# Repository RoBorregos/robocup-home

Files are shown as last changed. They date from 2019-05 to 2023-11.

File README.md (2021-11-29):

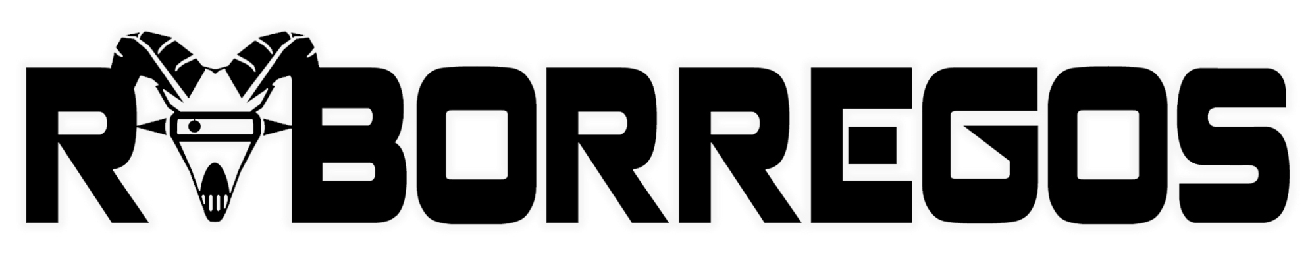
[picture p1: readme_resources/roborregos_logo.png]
 

# RoBorregos Robocup-Home
This repository contains the development of RoBorregos' robotic solution for [RoboCup's @HOME competition](https://athome.robocup.org/), Open Platform League (OPL), where the robot must be capable of interacting with people, manipulate objects and have intelligent responses for everyday home tasks.

See [RoboCup @HOME Rules](https://robocupathome.github.io/RuleBook/rulebook/master.pdf).

## Project setup

1. Clone the project repository on your local machine.

   SSH:

   ```bash
   $ git clone --recurse-submodules https://github.com/RoBorregos/Robocup-Home.git
   ```
2. [Docker Setup If needed](https://github.com/RoBorregos/Robocup-Home/wiki/Docker-Usage)

## Project details

This project is made using:
- [ROS Noetic](https://www.ros.org/)
- [Rasa NLU](https://rasa.com/)
- [Tensorflow](https://www.tensorflow.org/learn)
- [PaddlePaddle](https://github.com/paddlepaddle/paddle)
- [Arduino](https://www.arduino.cc/)
- [VIA EPIA](https://www.viatech.com/en/support/eol/epia-eol/)
- [Jetson](https://developer.nvidia.com/EMBEDDED/jetson-nano-developer-kit)

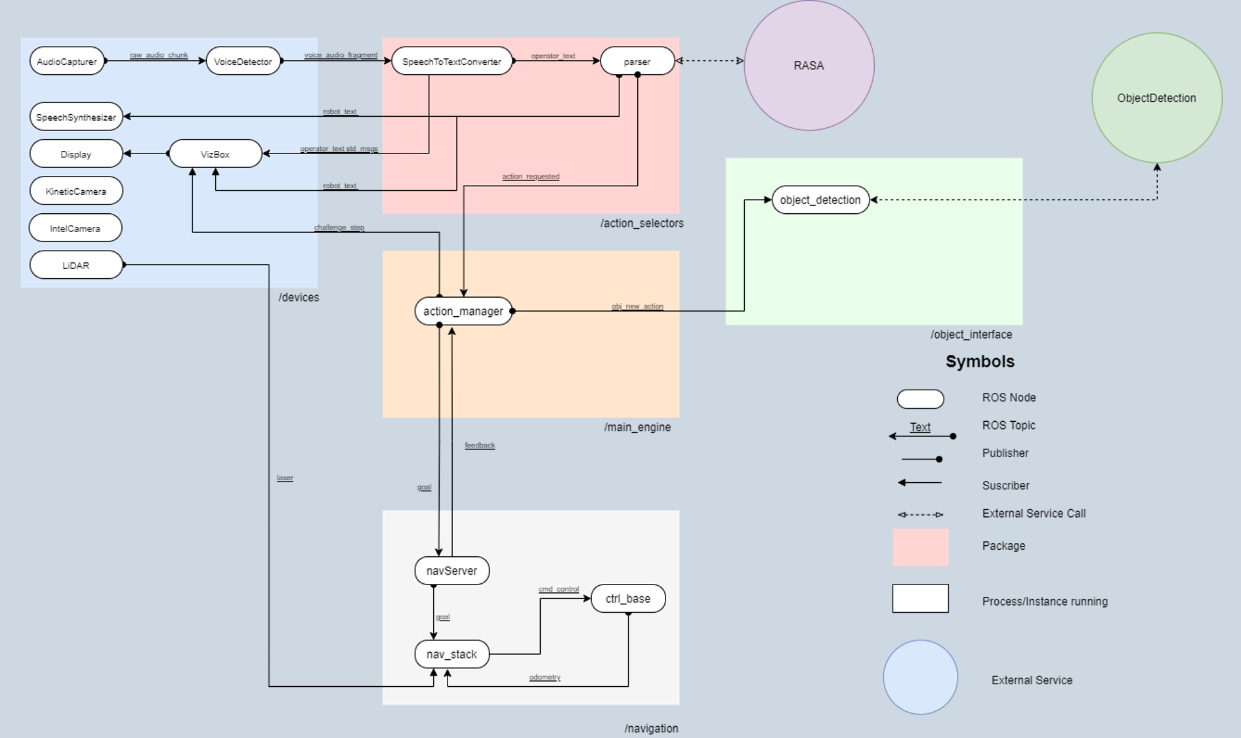
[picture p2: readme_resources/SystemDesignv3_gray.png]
 

For more information about the project system, structure, and development areas you can check our [Official Documentation](https://github.com/RoBorregos/Robocup-Home/wiki).

### Development team

| Name | Email | Github | Role |
| --- | --- | --- | --- |
| José Cisneros | [joseacisnerosm@gmail.com](mailto:joseacisnerosm@gmail.com) | [@Josecisneros001](https://github.com/Josecisneros001) | PM Software, Integration & Speech|
| Aldo Samaniego | [aldojesussam0@gmail.com](mailto:aldojesussam0@gmail.com) | [@AldoSamaniego](https://github.com/AldoSamaniego) | PM Mechatronics & Power Supply Electronics|
| Aurora Tijerina | [auro.tj@gmail.com](mailto:auro.tj@gmail.com) | [@AuroTB](https://github.com/aurotb) | Navigation & Integration |
| Ricardo Chapa | [ricardochaparomero@gmail.com](mailto:ricardochaparomero@gmail.com) | [@RicardoChapaRomero](https://github.com/RicardoChapaRomero) | Object Detection |
| Alejandro Ruiz | [alex.01ruiz@hotmail.com](mailto:alex.01ruiz@hotmail.com) | [@BVDozen](https://github.com/BVDozen) | Mechanical Design |
| Iqui Balam  | [iquibalamhm@gmail.com](mailto:iquibalamhm@gmail.com) | [@IquiBalamHM ](https://github.com/IquiBalamHM ) | Object Detection |
| Amin Mendez | [mendezamin.com@gmail.com](mailto:mendezamin.com@gmail.com) | [@AminMendez](https://github.com/AminMendez) | Mechanical Design | 
| Gaby Alvarez | [gabrielaj.alvarez@outlook.com](mailto:gabrielaj.alvarez@outlook.com) | [@gabyjazzmin ](https://github.com/gabyjazzmin ) |  NLP Conversation |
| Anel Alvarado | [anelgtz01@gmail.com](mailto:anelgtz01@gmail.com) | [@AnelAlvarado ](https://github.com/AnelAlvarado ) | Elevator Electronics |
| José Pacheco | [pacocheco7@gmail.com](mailto:pacocheco7@gmail.com) | [@JFPach98 ](https://github.com/JFPach98 ) | Human Detection |
| Alonso Ruiz | [alonsort11@gmail.com](mailto:alonsort11@gmail.com) | [@AlonRuiz](https://github.com/AlonRuiz) | Arm Mechanics |
| Andy Salcedo | [andrea2702@gmail.com](mailto:andrea2702@gmail.com) | [@andrea2702](https://github.com/andrea2702) | Arm Electronics |
| Ignacio Maldonado | [igna-tenkov@gmail.com](mailto:igna-tenkov@gmail.com) | [@IGNA-TENKOV](https://github.com/IGNA-TENKOV) | Mechanical Design |
| Paul Vazquez | [pev@live.com.mx](mailto:pev@live.com.mx) | [@paulvazbad](https://github.com/paulvazbad) | Mentor |

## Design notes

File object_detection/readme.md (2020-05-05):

# Train the Object Detection TF API from scratch using Google Colab
We are using the [TensorFlow Object Detection API](https://github.com/tensorflow/models/tree/master/research/object_detection) to retrain the models with the objects that we need. Check installation and more info there. All this has been tried for python2/3 and tensorflow==1.15.

[Colab](http://colab.research.google.com/) offers free access to a computer that has reasonable GPU good for training, it is a cloud service based on Jupyter Notebooks and internet connectivity is required for access.

## Preprocessing

The first step is to take pictures of the objects to train, after doing that, you have to reduce the resolution of the pictures (this reduces training time) and split the images into train/test folders.

run the [transform_image_resolution.py](https://github.com/RoBorregos/Robocup-Home/tree/develop/object_detection/scripts/transform_image_resolution.py) script:
```bash
python transform_image_resolution.py -d ../images/ -s 800 600
```
- `-d` is the directory containing all the images.
- `-s` is the resolution that will be applied to the images.

run the [split_images](https://github.com/RoBorregos/Robocup-Home/tree/develop/object_detection/scripts/split_images.py) script.
```bash
python split_images.py -d ../images/complete_dataset -o ../images --train 80
```
- `-d` is the directory containing all the images.
- `-o` is the directory where the train and test folder will be created.
- `--train` is the percentage of images that will be used for training, 80% for train and %20 for test is the recommended. 

Now you need to label the images, use the [labelimg](https://github.com/tzutalin/labelImg) open source tool to label all the pictures in both train/test directories (this is a tedious and long process).

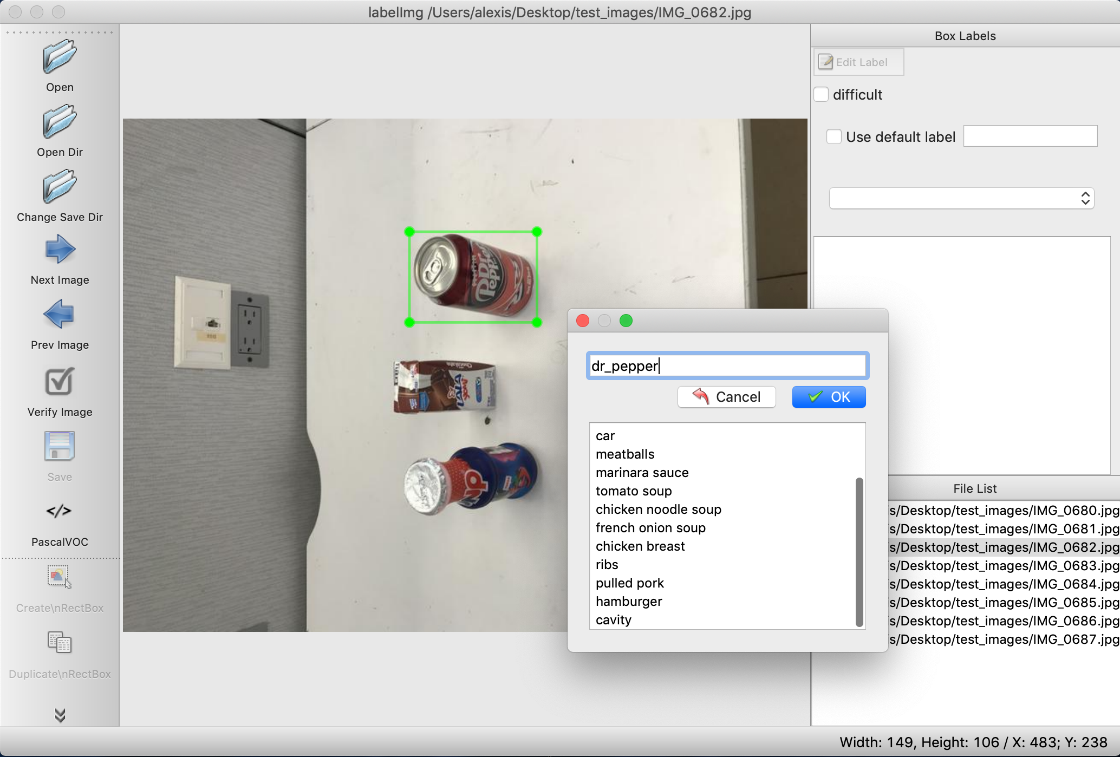
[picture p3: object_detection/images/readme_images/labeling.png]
labeling


**As of this point you should have a `image` directory that contains your train and test images with respective xml file of each images.**

Download the [generate_tfrecord.py](https://github.com/RoBorregos/Robocup-Home/tree/develop/object_detection/scripts/generate_tfrecord.py) script and change the `class_text_to_int` function by adding your own labels.
```python
def  class_text_to_int(row_label):
	if row_label ==  'powerade':
		return  1
	elif row_label ==  'chocolate':
		return  2
	elif row_label ==  'dr_pepper':
		return  3
	elif row_label ==  'danup':
		return  4
	else:
		None
```

Download the [labelmap](https://github.com/RoBorregos/Robocup-Home/blob/develop/object_detection/training/labelmap.pbtxt) file and change the `id` and `name` to your own labels. **NOTE:** Be consistent with the id you wrote on the `class_text_to_int` function.

We are using the Faster-RCNN-Inception-V2 model. [Download the model here.](http://download.tensorflow.org/models/object_detection/faster_rcnn_inception_v2_coco_2018_01_28.tar.gz) Open the downloaded faster_rcnn_inception_v2_coco_2018_01_28.tar.gz file with a file archiver and extract the faster_rcnn_inception_v2_coco_2018_01_28 folder.

Download the [faster_rcnn_inception_v2_pets](https://github.com/RoBorregos/Robocup-Home/blob/develop/object_detection/training/faster_rcnn_inception_v2_pets.config) file. Here you can find several parameters like batch size, learning rate, etc. Then, change:

- Line 9. Change `num_classes` to the number of different objects you want the classifier to detect.
- Line 130. Change `num_examples` to the number of images you have in the `\images\test` directory.

## Setup Google Colab Notebook

* Create a directory in your google drive.
* Download the [train_model](https://github.com/RoBorregos/Robocup-Home/tree/develop/object_detection/train_model.ipynb) notebook from the RoBorregos @Home repo.
* Go to Colab, sign in with the same account you used to create the directory, create a new notebook and open the train_model notebook.
* In the notebook go to Runtime > Change Runtime Type and make sure to select GPU as Hardware accelerator.
* Click connect to start using the notebook

The first command is to check if you are using GPU.
```python
import tensorflow as tf

device_name = tf.test.gpu_device_name()
if device_name != '/device:GPU:0':
	raise  SystemError('GPU device not found')
print('Found GPU at: {}'.format(device_name))
```
You should see `Found GPU at: /device:GPU:0`

The second command is to mount Google Drive with the notebook, click on the link. Then sign in with your google drive account, and grant it access. you will be redirected to a page, copy the code on that page and paste it in the text-box of the Colab session you are running.

The following commands are very straightforward, just make sure to change the paths by replacing the name of your folder.
E.g:
```bash
cd /content/gdrive/My Drive/@Home/models/research/
```
To:
```bash
cd /content/gdrive/My Drive/Your_Folder/models/research/
```

After cloning the repo, you have to upload the previous files you edited to the `object_detection` folder.

- Upload the `generate_tfrecord.py` script to `your_folder/models/research/object_detection`
- Download the [xml_to_csv.py](https://github.com/RoBorregos/Robocup-Home/tree/develop/object_detection/scripts/xml_to_csv.py) script and upload it to `your_folder/models/research/object_detection`
- Create a folder in `your_folder/models/research/object_detection` named `training` and upload the `labelmap.pbtxt` and `faster_rcnn_inception_v2_pets.config` files.
- Create a folder in `your_folder/models/research/object_detection` named `images` and upload the test/train folders containing the images and xml files.
- Upload the `faster_rcnn_inception_v2_coco_2018_01_28` folder to the `object_detection` folder.

Follow the notebook and continue with the commands.

## Training 

Once you run the `xml_to_csv` and 	`generate_tfrecords` scripts, the next step is to run the `train.py` script to start the training, just keep following the notebook and after you run the train script in absence of errors, you should see and output like this:

```
INFO:tensorflow:global step 1: loss = 25.45 (5.327 sec/step)

........  
........

INFO:tensorflow:global step 1350: loss = 0.6345 (0.231 sec/step)  
INFO:tensorflow:global step 1351: loss = 0.5220 (0.332 sec/step)  
INFO:tensorflow:global step 1352: loss = 0.6718 (0.133 sec/step)  
INFO:tensorflow:global step 1353: loss = 0.6758 (0.432 sec/step)  
INFO:tensorflow:global step 1354: loss = 0.7454 (0.452 sec/step)  
INFO:tensorflow:global step 1355: loss = 0.8354 (0.323 sec/step)
```

As we are running this in Colab, with 3-4 hours its pretty enough, every 5 minutes aprox the changes are automatically saved in the `training` folder. Stop the training with `CTRL + C`.

The final step is to export your inference graph, the command is already in the notebook, the only thing you have to change is the `--trained_checkpoint_prefix` flag.  Go to the `training` folder and you will see some of the last checkpoints the model saved, copy the `id` of the last checkpoint and change it on the command:
`--trained_checkpoint_prefix training/model.ckpt-158879`

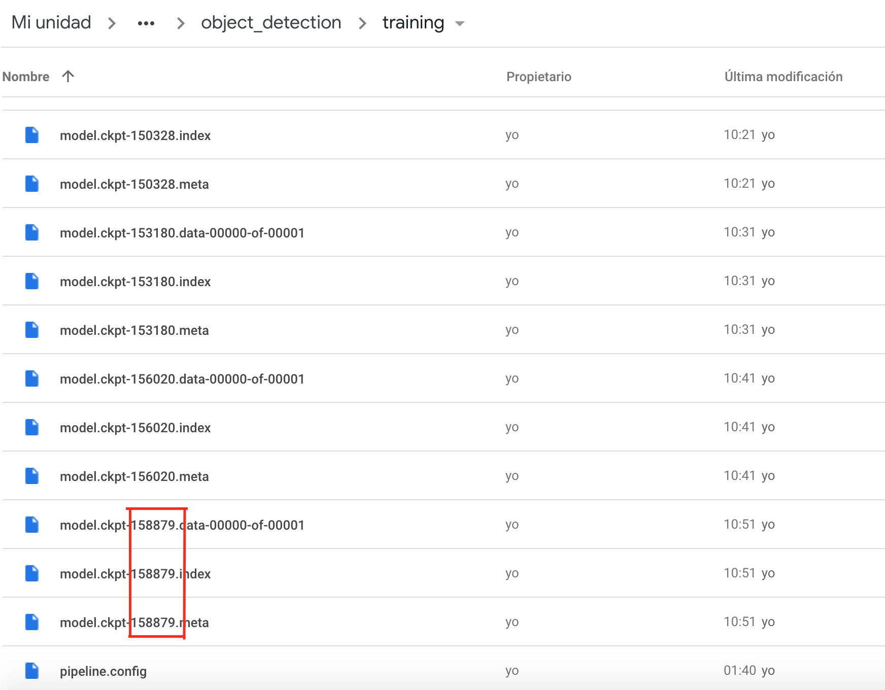
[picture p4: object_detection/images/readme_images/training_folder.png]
traning_folder


Finally, you can run the code in the last shell of the notebook to test your model, take new pictures to test the model and place them on a folder named `test_images`. Remember you should use for inference at least the same tf version that the one used for training.

Change the `IMAGE_NAME` on the script:
```python
IMAGE_NAME = 'test_images/IMG_0681.jpg'
```

Run the shell, you should see the image with the objects detected:

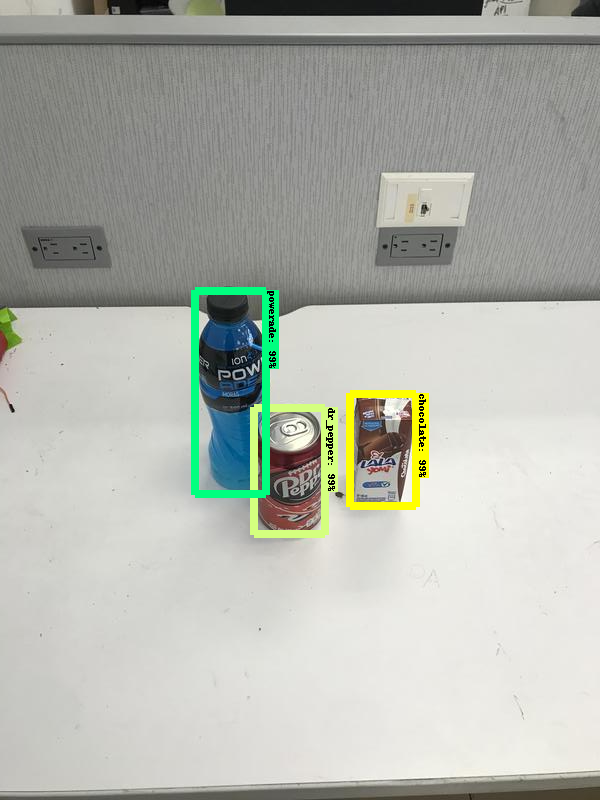
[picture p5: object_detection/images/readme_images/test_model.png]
test_model


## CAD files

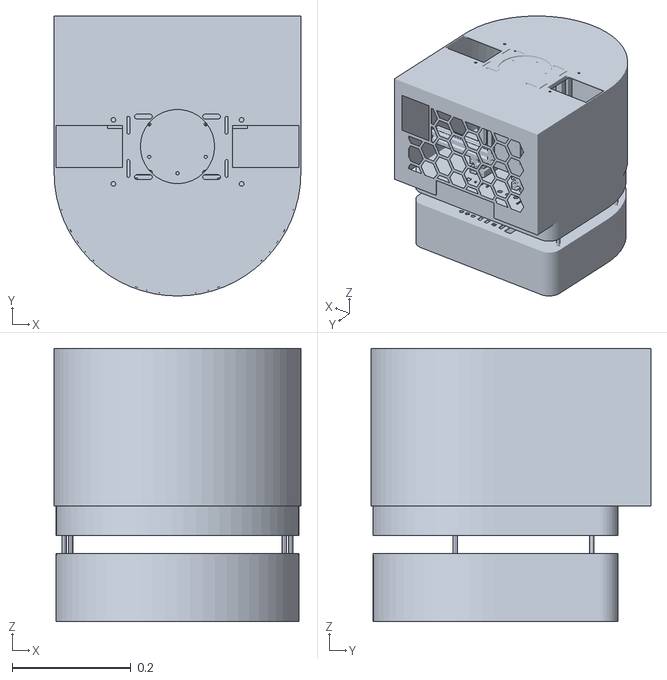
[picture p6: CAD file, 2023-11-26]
catkin_home/src/robot_description/meshes/Dashgo/dashgo_cubierta.stl
0.416 x 0.472 x 0.461

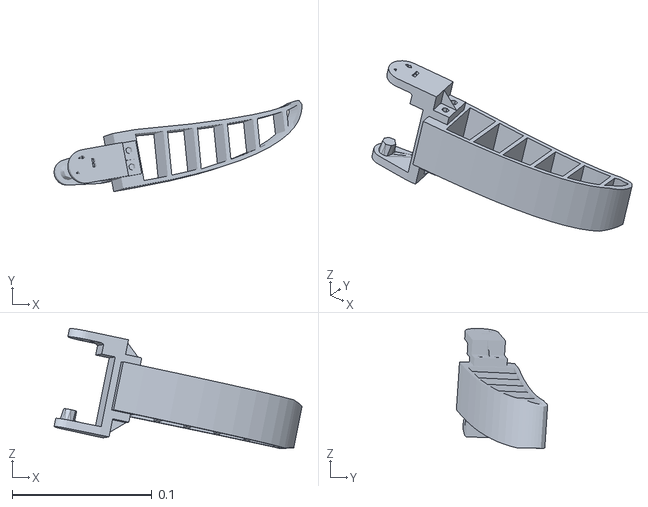
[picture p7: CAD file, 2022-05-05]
catkin_home/src/robot_description/meshes/Garra_D.STL
0.177 x 0.0652 x 0.0858

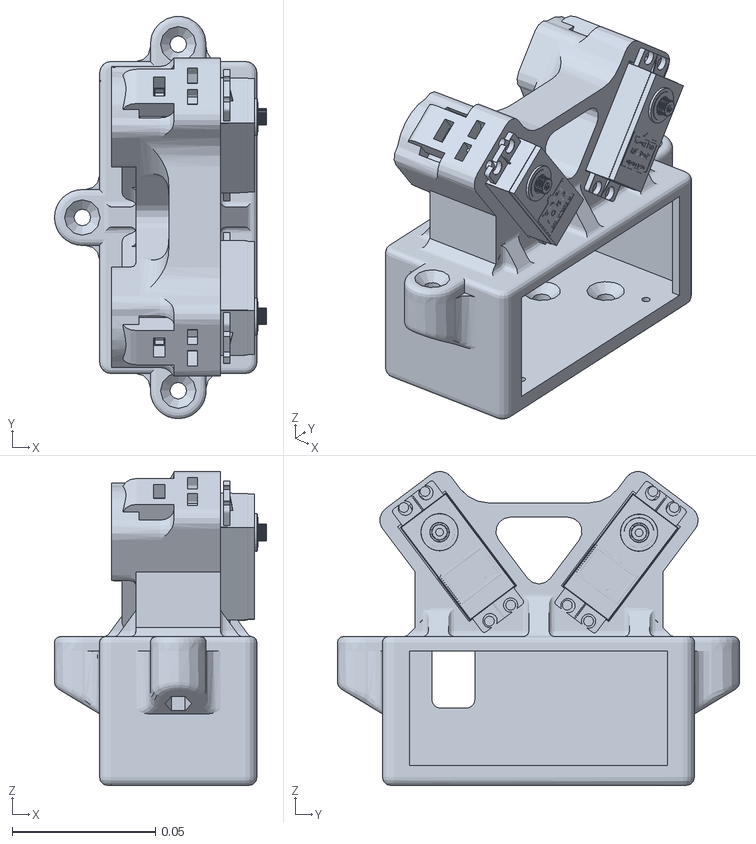
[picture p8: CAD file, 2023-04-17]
catkin_home/src/robot_description/meshes/Gripper/Base.STL
0.0741 x 0.141 x 0.11

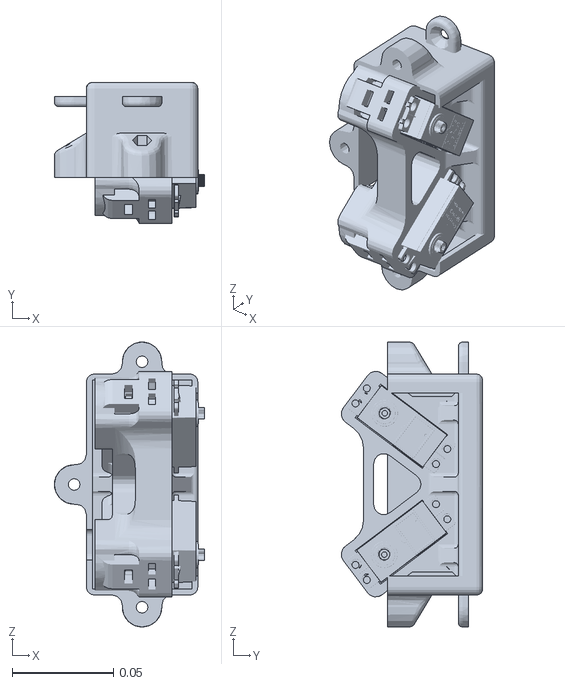
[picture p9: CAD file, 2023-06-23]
catkin_home/src/robot_description/meshes/GripperFakeSF/Base_Gripper.STL
0.0741 x 0.0697 x 0.141

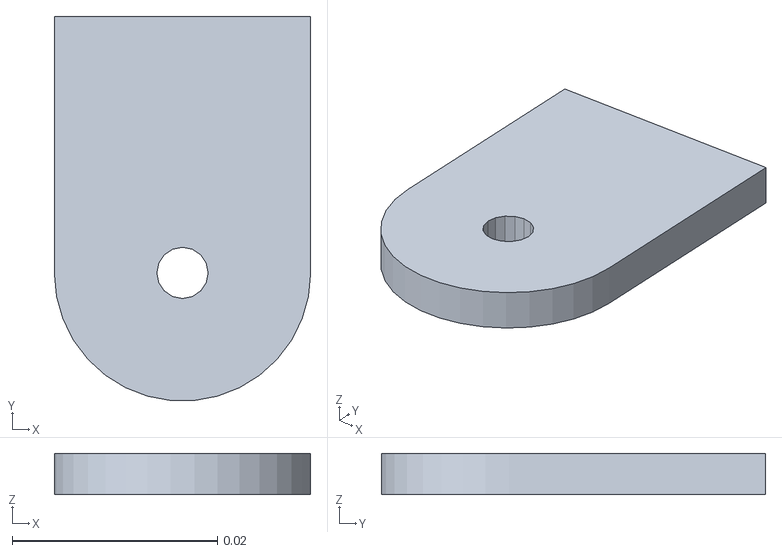
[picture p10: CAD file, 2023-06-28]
catkin_home/src/robot_description/meshes/GripperSF/Servo1.STL
0.025 x 0.0374 x 0.004

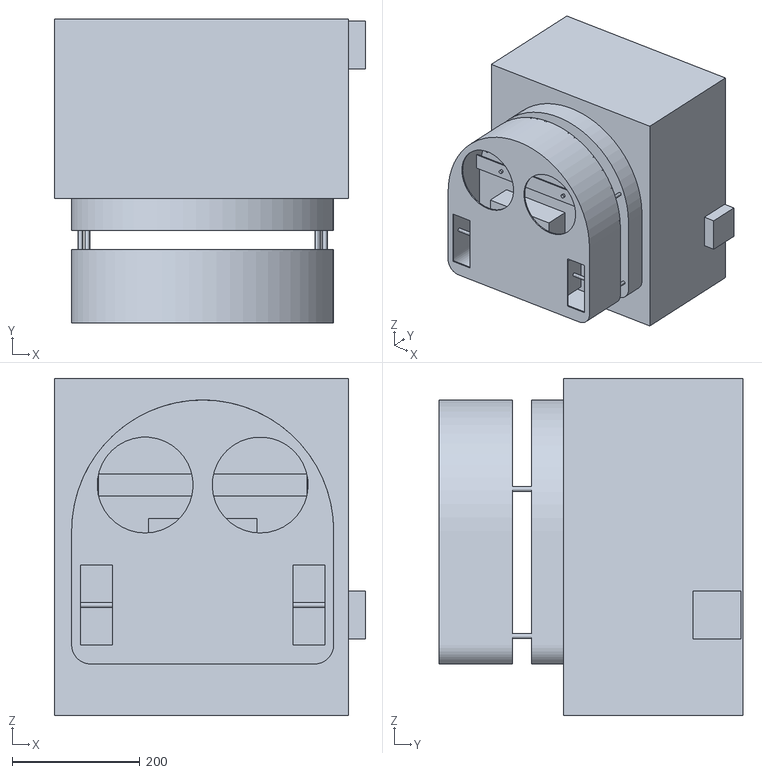
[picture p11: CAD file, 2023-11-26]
catkin_home/src/robot_description/meshes/Dashgo/cubierta_colliders.stl
487.1 x 475.5 x 527.2

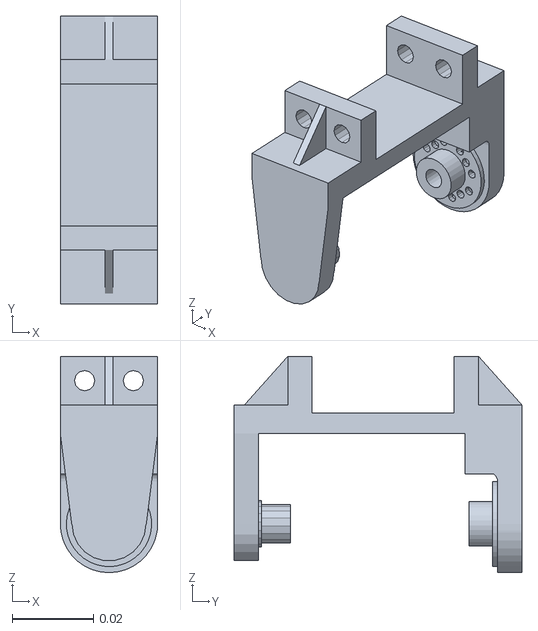
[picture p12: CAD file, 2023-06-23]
catkin_home/src/robot_description/meshes/GripperFakeSF/Servo2.STL
0.024 x 0.0709 x 0.0533

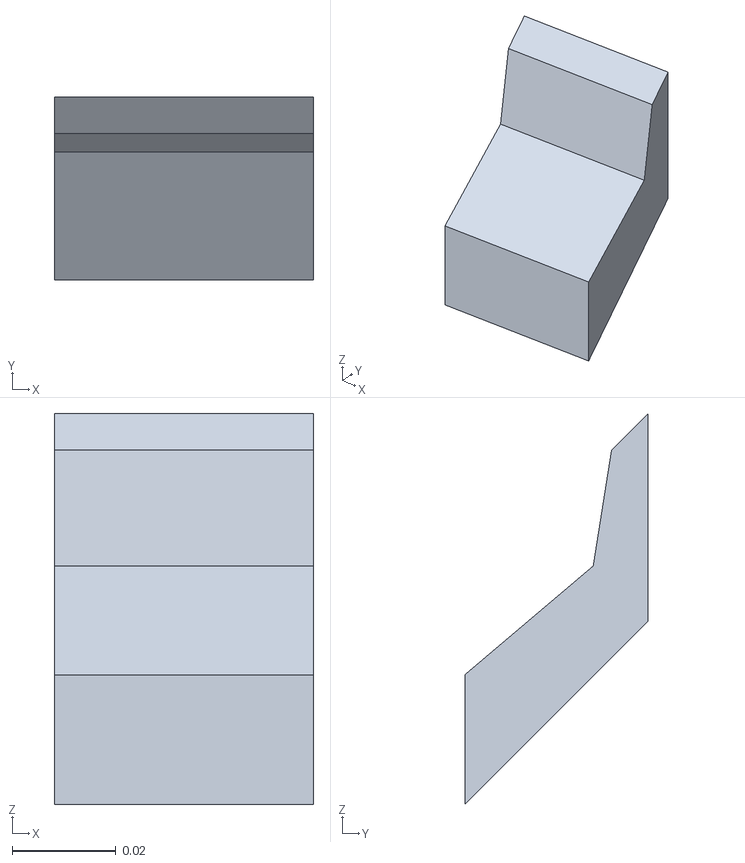
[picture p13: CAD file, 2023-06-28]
catkin_home/src/robot_description/meshes/GripperSF/Dedo2.STL
0.05 x 0.0354 x 0.0754

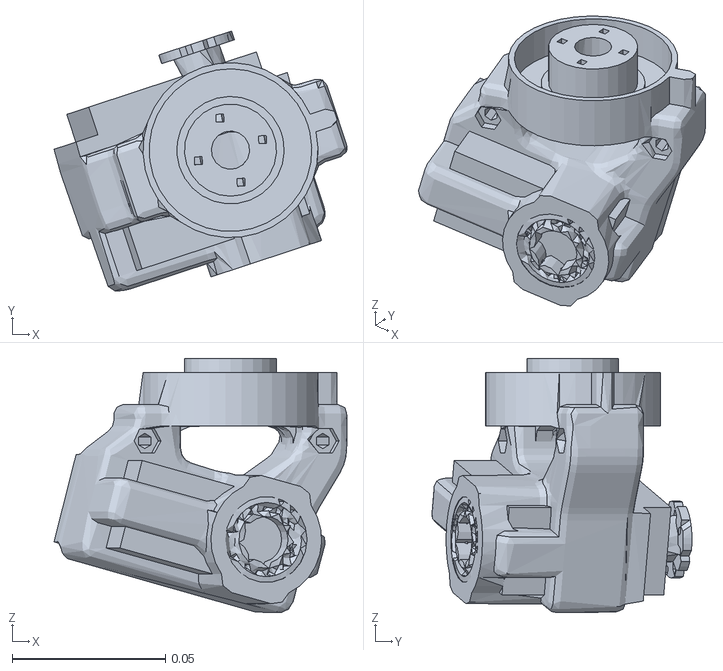
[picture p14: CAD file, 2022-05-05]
catkin_home/src/robot_description/meshes/Pinza.STL
0.0955 x 0.0847 x 0.0828

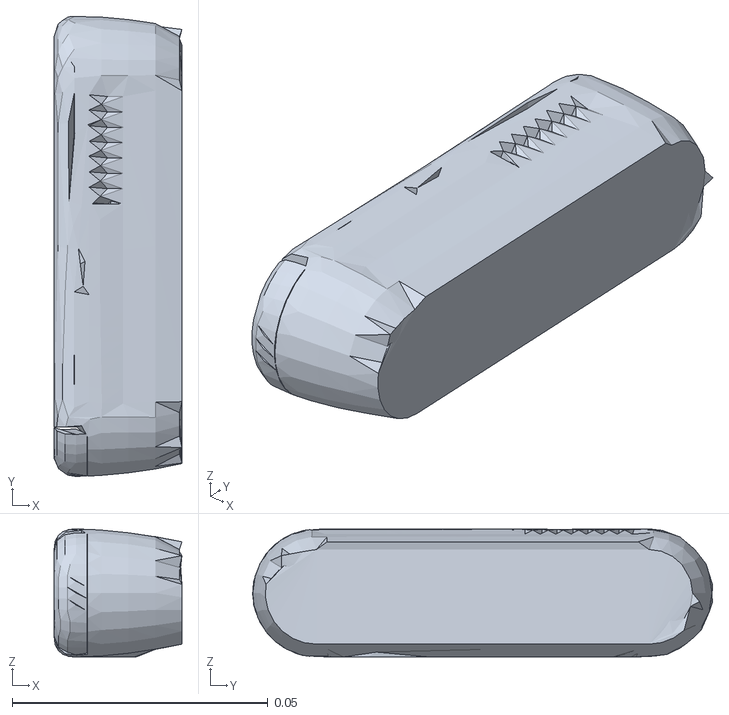
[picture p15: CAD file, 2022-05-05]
catkin_home/src/robot_description/meshes/Camara.STL
0.025 x 0.0899 x 0.025

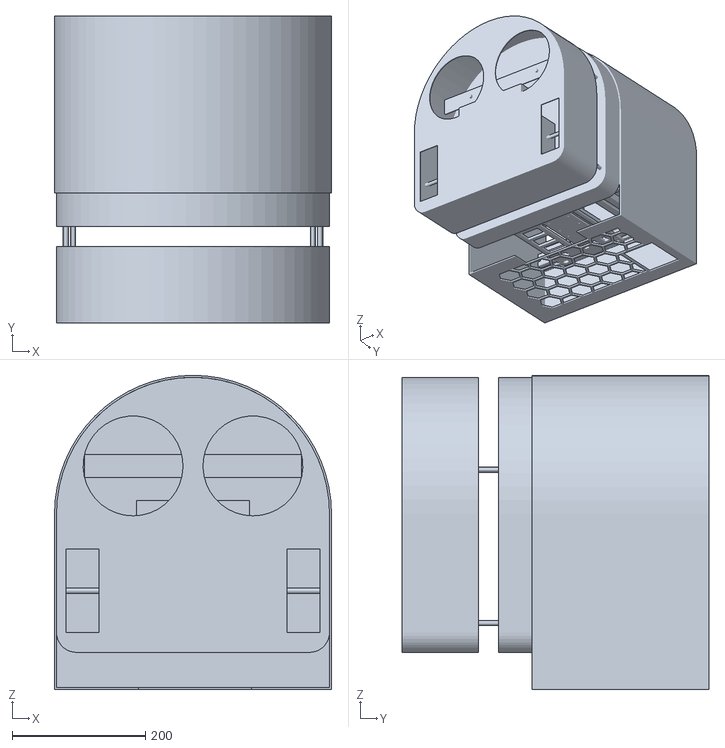
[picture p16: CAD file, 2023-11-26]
catkin_home/src/robot_description/meshes/Dashgo/cubierta.stl
416.0 x 461.0 x 472.0

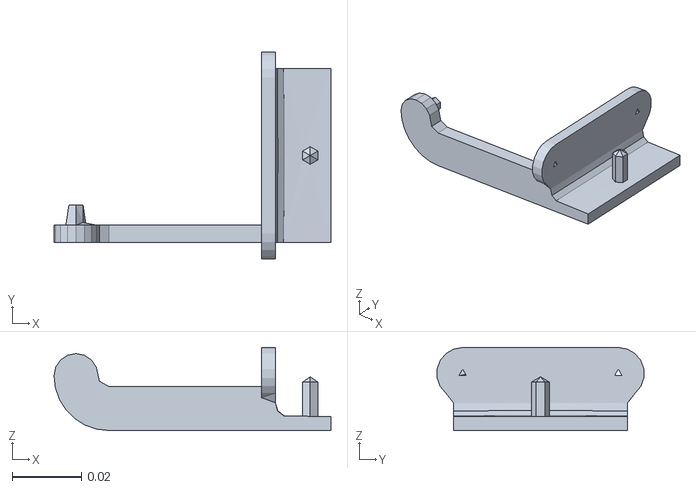
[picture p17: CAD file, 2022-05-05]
catkin_home/src/robot_description/meshes/Cuello.STL
0.0801 x 0.0598 x 0.024

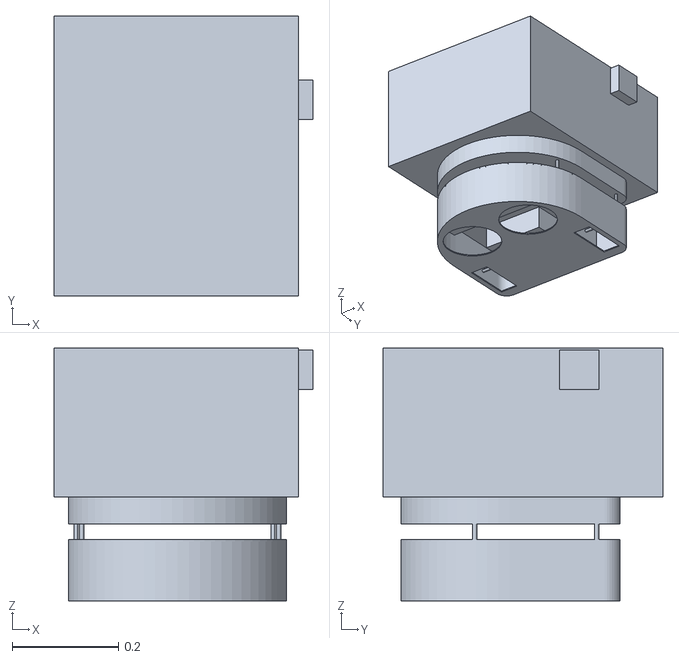
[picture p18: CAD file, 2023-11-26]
catkin_home/src/robot_description/meshes/Dashgo/dashgo_cubierta_colliders.stl
0.487 x 0.527 x 0.476

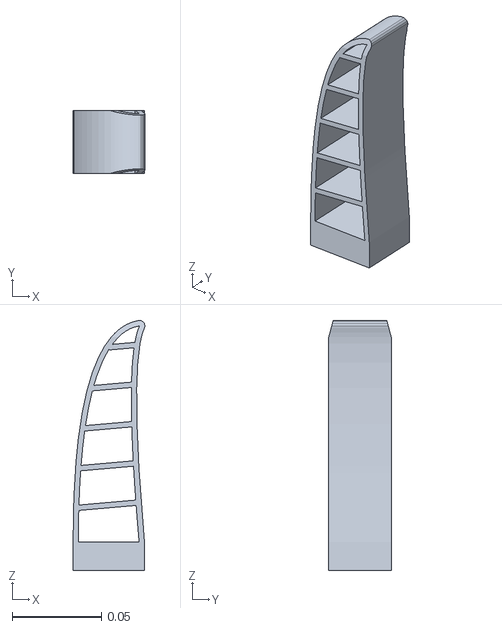
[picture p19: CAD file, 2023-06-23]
catkin_home/src/robot_description/meshes/GripperFakeSF/Dedo2.STL
0.0403 x 0.035 x 0.14

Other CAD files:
catkin_home/src/robot_description/meshes/GripperP/BaseGri.STL
catkin_home/src/robot_description/meshes/GripperFakeSF/Servo1.STL
catkin_home/src/robot_description/meshes/GripperSF/Servo2.STL
catkin_home/src/robot_description/meshes/GripperSF/Base_Gripper.STL
catkin_home/src/robot_description/meshes/BASE_PINZA.STL
catkin_home/src/robot_description/meshes/Dashgo/BaseCollisionsSinPalo.stl
catkin_home/src/robot_description/meshes/Dashgo/BaseSinPalo.stl
catkin_home/src/robot_description/meshes/Garra_I.STL
catkin_home/src/robot_description/meshes/Gripper/Dedo1.STL
catkin_home/src/robot_description/meshes/Gripper/Dedo2.STL
catkin_home/src/robot_description/meshes/Gripper/Servo1.STL
catkin_home/src/robot_description/meshes/Gripper/Servo2.STL
catkin_home/src/robot_description/meshes/GripperFakeSF/Dedo1.STL
catkin_home/src/robot_description/meshes/GripperFakeSF/Dedo1_.STL
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

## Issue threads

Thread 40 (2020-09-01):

Get the 3D image segment of the desired object from the 2D one.

paulvazbad, 2020-09-01:
integrate Cardozo + Iqui to generate 3D image based on 2D image.

Deliverable: PR

tomvik, 2020-09-12:
@paulvazbad this is being blocked mainly by PR #35
Also, by the fact that @diegocardozo97 hasn't uploaded his branch with his experiments with the camera, which could help as ground work for us.

paulvazbad, 2020-09-13:
I have reviewed PR #35 have you talked to @diegocardozo97? I can ping him too if needed.

tomvik, 2020-09-15:
Now that the PR #35 has been merged, these are the next steps:
1. Check Cardozo's [vision_intel_segment](Robocup-Home/tree/vision_intel_segment) branch and merge whatever is useful
2. Refactor the existing arm_vision package to follow the C++ style guide

paulvazbad, 2020-09-22:
Are you going to work on both things for the remaining time of this sprint?

tomvik, 2020-09-22:
That's the plan, but I'm unsure on how much I can complete.

tomvik, 2020-09-29:
As a follow up:
1. I'm checking Cardozo's branch, soon I should be able to give a LGTM to submit that PR.

2. The refactoring of the existing package is something that @IquiBalamHM was checking, according to our last meeting.

tomvik, 2020-10-08:
Currently working on refactoring Cardozo's code with the new Python standard.

Closed 2020-10-13.

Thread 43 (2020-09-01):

Draft de las medidas + diseño generico

paulvazbad, 2020-09-01:
Investigar/Hacer algún tipo de estudio para determinar la posición más activa de la pantalla en el robot. Esto involucra integrar con el diseño actual de Aldo y Amin.

Draft de las medidas de los componentes involucrados

Deliverable: Lista, sketch, de las medidas y componentes que afecta la cabeza + pantalla.

paulvazbad, 2020-09-15:
- Made CAD of the central microphone.
- Determined the optimal position for the screen.
-  Focussing on the face and head.

Deliverable links:

paulvazbad, 2020-09-17:
@GabrielaMl please add the links to the evidence/deliverables as a comment to this issue.

GabrielaMl, 2020-09-17:
https://tecmx-my.sharepoint.com/:f:/g/personal/a00825779_itesm_mx/Evrr53hF_7ZPtyLyytkLh-YBqMsqpydhdm7eCWHFch57jg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

Closed 2020-09-15.

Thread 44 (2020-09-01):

Conversation demo chatbot

paulvazbad, 2020-09-01:
Iniciar investigación del programa RASA.
Iniciar etapa de aprendizaje respecto a las funcionalidades que se pueden lograr y aportar al equipo.
Investigar e instalar herramientas necesarias para el desarrollo esperado.

Leyeran la documentacion main_engine

Deliverable: Demo Chatbot with stories, domain information and forms.

paulvazbad, 2020-09-15:
*Updates*
Aurora gave a seminar/talk/presentation on how RASA works.
Initial testing of RASA.
Installation of WSL.

Closed 2020-10-13.

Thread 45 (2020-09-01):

Arm drivers: testing

paulvazbad, 2020-09-01:
Test different drivers to improve performance and reliability of the arm.

Deliverable: Doc with information about the new drivers: current A4988, 2208, 2209.

paulvazbad, 2020-09-15:
*Tested*
 Articulations? 1 y 4
 A498
 DRV8825

New drivers:
TMC2208

Closed 2020-09-15.

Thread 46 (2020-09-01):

Elevator Part 1

paulvazbad, 2020-09-01:
Investigation:  What type of elevator is best for our application.
CAD of the Elevator.

Deliverable: CAD of the elevator and documentation of reasoning behind the chosen type etc...

paulvazbad, 2020-09-15:
Changed to new design follow up in next sprint, adding new info to new BOM.

Closed 2020-09-15.

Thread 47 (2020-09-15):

Follow up on issue #46 (New elevator)

paulvazbad, 2020-09-15:
Deliverable: CAD of new design + BOM of parts required.

Closed 2020-10-13.

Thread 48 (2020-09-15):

3d Printing Joints

paulvazbad, 2020-09-15:
- Joints 5 and 6.

paulvazbad, 2020-09-29:
@Lufergvera please post a picture here to have evidence going forward.

Closed 2020-09-29.

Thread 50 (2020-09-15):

Initial work on main engine + parser

paulvazbad, 2020-09-15:
What needs to be done and how it should be done.

Deliverable: Document of planned changes to the parser + main engine to complete 2 challenges of stage 1.

Deliverable: Up and running the parser module and main engine.

paulvazbad, 2020-09-29:
@gabyjazzmin @alexisavz please include here the document that you mentioned to close this issue

gabyjazzmin, 2020-09-29:
This is the document that we mentioned, here we defined the challenges of stage 1 that we're going to work through this semester https://docs.google.com/document/d/1aLKYcb8XwO975N9op4Mj2bEjEWM1cx5lk2PdpYGhH9k/edit?usp=sharing

Closed 2020-10-13.

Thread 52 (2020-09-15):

Odometry of the robot

paulvazbad, 2020-09-15:
Testing odometry in the robot (IRL).

Deliverable: PR and wiki entry.

paulvazbad, 2020-09-28:
Awesome work @Josecisneros001 I will close this issue

Closed 2020-09-28.

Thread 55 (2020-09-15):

Set up of Kinect in ROS

paulvazbad, 2020-09-15:
Migrating from Intel camera to Kinect.

Deliverable: PR

tomvik, 2020-09-15:
@IquiBalamHM and I were discussing briefly about the following two ideas:
1. Maybe it is possible to record a video or a set of photos with Intel's camera so he can use that for processing. More research needs to be done in order to find out if that's possible.
2. Either way, whether we're using the Kinect, Intel's camera, or any other camera, it would be nice to have the code in such a way that the **meat** of the code is immutable to the camera. Perhaps the processing, once the point cloud is extracted, could be the same for all cameras, or differing in some small parts.

paulvazbad, 2020-09-17:
I think related to the second point is the idea behind having the image capturing in the package devices/imageCapture.py . As of today, it is considered to have the processing completely separated from the image capture by subscribing to the topic `frames` that this node creates.

There is also a b
Take a look into [imageCapture.py](https://github.com/RoBorregos/Robocup-Home/blob/develop/catkin_home/src/devices/scripts/imageCapture.py)

There is still a TODO to implement this logic but the system architecture is ready to handle this change
`#Default webcam
# 0 --- Integrated
# 2 --- Intel B/W
# 3 --- Intel Color
CAMERA = 0`

tomvik, 2020-09-29:
As mentioned on the issue #40 I believe @IquiBalamHM is currently working on refactoring the current arm_vision package to make it modular.

tomvik, 2020-10-20:
@IquiBalamHM can you write some update in here?

Closed 2021-01-31.

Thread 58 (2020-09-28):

Arm vision package breaking build

paulvazbad, 2020-09-28:
Steps to recreate:
1. checkout to develop
2. run catkin make
3. an import error appears in the arm vision package.
Image related:
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

tomvik, 2020-09-28:
Basically I didn't catch the error because under my devel folder I still had the my_pcl_tutorial/SegmentedClustersArray msg that was generated when building Iqui's original PR where the package had the name my_pcl_tutorial.

Closed 2020-09-29.

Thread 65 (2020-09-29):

Torque calculation and security of the robot

paulvazbad, 2020-09-29:
- Check that the robot has the correct dimensions and that the torque in the elevator is wont make it fall over someone.
- Calculate how much does it take for the robot to reach the top.

paulvazbad, 2020-10-10:
@AminMendez @Lufergvera @AldoSamaniego please add to this issue updates on the subject:
Calculations done, modifications to the design, security risks detected, etc....

AminMendez, 2020-10-13:
https://docs.google.com/spreadsheets/d/1PbO1ljPmfABfIhJFhoARIgWsTb2fUlrairehncUXbyM/edit?usp=sharing

Analisis of Ball Screw and Rollover.

We found that with the current design the robot can experience Rollover when stopped inmediately at velocity of 0.7 m/s or higher. Due to the max velocity of the motor is 0.45 m/s, the mechanical team is going to change the design by adding an extra load at the back to lower the center of gravity or change the upper structure including the robot arm.

Closed 2020-10-13.

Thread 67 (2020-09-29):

Connect odom frame with simulation in RVIZ

AuroTB, 2020-09-29:
Objectives:
- Make the robot simulation move with IRL movements fo the encoders by sending odom/ frame transform.
- Make these movements be attached to a map provided by the map server.
Extra:
- Have the ability to approximate by meters the movements made.

Deliverables
- [x] PDF image of the transform tree
- [x] Video demo

AuroTB, 2020-10-27:
- Looking at the python Lint docs (for #82)

Closed 2021-04-07.

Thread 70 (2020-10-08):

Continuous Integration setup (testing)

tomvik, 2020-10-08:
Deliverables:
* Modified github action to run tests
* Some proof-of-concept tests

tomvik, 2020-10-20:
And the work made by @paulvazbad in #73 was extremely helpful as groundwork for our packages

tomvik, 2020-10-20:
This Issue is a followup of #64

Closed 2020-10-27.

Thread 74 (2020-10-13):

Integration of base control

paulvazbad, 2020-10-13:
Simulation reflects real-life movement (simulation + control of the robot)

rqt_graph

AuroTB, 2020-10-27:
Solved some problem with the connection of a motor.
Looking at the python Lint docs.

Closed 2021-04-07.

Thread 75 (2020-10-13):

Calculate max height of the arm

paulvazbad, 2020-10-13:
Deliverable: Spreadsheet of calculations regarding the height of the arm in the robot.

**Necessities of the robotic system in general**
- Motor calculations
- Stepper pressure/inertia/torque/force

Closed 2020-11-10.

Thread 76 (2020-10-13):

Prototyping new arm

paulvazbad, 2020-10-13:
Print the pieces of arm
Deliverable: Photos of the pieces and documentation of the process.

AuroTB, 2020-10-27:
Luis printed some pieces and it's trying to ramp up into using resin to print some pieces (gears)
He's thinking of also doing some modifications to the process (resine stractor) and experimenting with the process.

Lufergvera, 2020-11-24:
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
I've been some tests with resin gears (washable in water) and I solved ringing problems in the fdm pieces

Closed 2023-11-03.

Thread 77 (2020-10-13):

Integrate arm to the robot

paulvazbad, 2020-10-13:
Deliverable: CAD of the robot including the new design arm.

AminMendez, 2020-10-27:
The integration of the Arm/Elevator to the base still in progresss. We do several modification to the chasis structue, and we open the posibility to the arm to reach the floor. Also we modificated the Scara Arm to satisify the challenges and mantain stability, such as lenght, supports and arm base.

We have some problems to place the kinect base and it stilled floated, but we are going to design a 3d printed base from the chasis in order to place it.

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

Closed 2020-11-10.

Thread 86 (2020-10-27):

Test Migration to ROS Noetic

tomvik, 2020-10-27:
This may be a part 1 of 2, where the end goal is to move the project to ROS2.

Why go through ROS Noetic first? As recommended by ROS' webpage:

**This may be a good (optional) first step if you want to make the transition to ROS2 Foxy from ROS1 Kinetic or ROS1 Melodic. You can first port your ROS1 code to ROS1 Noetic and make sure everything works with Python3. Then, you can switch to ROS2.**

tomvik, 2020-10-27:
As talked with Paul privately; #85 is already functioning with:
- CI build and test
- main_engine

However, the rest of the scripts need to be tested for python3 compatibility and for that I'd need help of the people who wrote them or know how to run them @paulvazbad @AuroTB @RicardoChapaRomero

AuroTB, 2020-10-28:
Today we checked nav's action provider script and Nav Stack launch and everything ran successfully.
Other than that, Tommy had to install directly _navigation_, so that might have to be added to CI run actions (we'll have to make some tests).

paulvazbad, 2020-11-08:
I'm currently updating my Ubuntu from 18 to 20 and my ROS distribution from melodic to noetic. I'll let you know when I'm done so I can look into the python2 scripts that are outdated.
Side note: @Josecisneros001 mentioned that there are packages in speech that require python2, but he might have a 'hack' to fix that.

Josecisneros001, 2021-09-18:
Reference : #115

Closed 2021-09-18.

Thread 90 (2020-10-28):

Calculate rollover of new robot design

AuroTB, 2020-10-28:
Calculate force/momentum according to the robot's new points of center mass created by the arms/base.
- Rotating robot
- Moving robot

(idk plz edit this issue)

AminMendez, 2020-11-24:
In order to calculate the roll over in certain circumstances first we need to calculate the center of gravity and inertia.

In case of crash or Unespected stop.

The emergency boton will stop the wheels inmediatly causing the robot transform its kinetic energy into potencial energy trying to rotate the robot. Using SolidWorks mass properties we can determine it with respect of the wheels. We can use the same point in case of a lower zone crash.

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

In conclusion of the result, we can know that maximum velocity at which the robot can move with the actual structure, the arm at its hight position and stop without falling is 0.9 meters per second

Closed 2021-01-26.

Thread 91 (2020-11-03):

Change the motors

paulvazbad, 2020-11-03:
The robot's current motors are too slow with a velocity of approx 0.2 m/s, when the goal is of at least 0.43 m/s.
Adding @mechanics to the issue to help with the specs of the motoros.

Josecisneros001, 2020-11-03:
To get a speed of at least 0.43 m / s, we need some motors that are over 82 RPM.
(Pololu motor list)[https://www.pololu.com/category/116/37d-metal-gearmotors]
(I think this could be the one)[https://www.pololu.com/product/4755]
It would be great if any of you could calculate the torque required to move the robot.
@AminMendez @AldoSamaniego @BVDozen

Josecisneros001, 2020-11-03:
[This is the current motor](https://www.amazon.com/CQRobot-Encoder-Mounting-Bracket-80Kg-cm/dp/B0731MD6JL)

AminMendez, 2021-02-17:
The required torque to move the robot is a torque greater than the force of friction that go against the movement. Due to the design of the chasis this friction occurs between the motor shaft and it's cage. This friction coefficient is difficult to calculate theoritacally. We can estimate the value by knowing the actual weight and the force acting on the motor by applying the formula of equilibrium. To help our calculus we can use the torque vs speed chart of our current motor at nominal voltage 12V. If we apply 12V at motor and friction are not consider we expect that motor rotate at 40 rpm as the datasheet mention, but when load is applyied this rpm will reduce. The force acting against can be know by analyzing the chart and see the rpms the wheel does at a constant load. Once knowing the the force of friction we divide this value by the normal force, in this case the current weight of the robot.

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

Future design may include bearings to reduce this value of friction and improve robot movement.

The motor propose by Cisneros is a good candidate for the replacement of the robot. with an initial acceleration of 0.952 m/s^2, max torque of 34 kgcm and max speed with no load of 100 rpms considering 70 kg of weight

Another candidate could be this one
https://www.amazon.com/-/es/CQR37D64CPR131-3GR/dp/B0876CYVCC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

with an initial acceleration of 1.26 m/s^2, max torque of 45 kgcm and max speed with no load of 83 rpms

Josecisneros001, 2021-09-18:
Solve - Missing one motor.

Closed 2023-11-03.

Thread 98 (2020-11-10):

Emergency button

paulvazbad, 2020-11-10:
Deliverable:
CAD and Photos

LorenaMGP, 2021-10-02:
### **Emergency button**

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

### **Reference**

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
[Reference](https://www.se.com/es/es/product/XB4BS8445/paro-de-emergencia%2C-metal%2C-seta-roja%2C-%C3%B840%2C-%C3%B822%2C-giro-del-gatillo-para-liberar%2C-1-no-%2B-1-nc/)

### **Emergency button support**

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

### **Example**

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

### **Some distributors**
[Electrónica universal](https://www.electronicauniversal.com.mx/tienda/botoneras/hpq01k/)
[Lionchip](https://www.lionchipmexico.com/product-page/boton-de-paro-de-emergencia-no-nc-22-mm-plc-push-normalmente)
[Mercado libre](https://articulo.mercadolibre.com.mx/MLM-594492515-boton-paro-de-emergencia-con-enclavamiento-_JM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)

Closed 2023-11-03.

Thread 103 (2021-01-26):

PCB Electronica Potenica

Josecisneros001, 2021-01-26:
Objectives:
-  Investigación sobre los módulos de robot y sus demandas energéticas.
-  Esquemático

De acuerdo al esquemático: [https://oshwlab.com/a00825779/home-base]
Poner a disposición:
 - 5V, 12V
 - Pines que no se usan del microcontrolador.
 - Pines I2C

Deliverables
- [ ] Documento Drive
- [ ] Link EasyEda

AldoSamaniego, 2021-03-17:
https://oshwlab.com/a00825779/home-base @Josecisneros001

Closed 2023-11-03.

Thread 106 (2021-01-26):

PCB Base - Testing Schematic

Josecisneros001, 2021-01-26:
Objectives:
- Probar componentes: 3.3V-5V Logic Converter, I2C with ESP32
- Rediseñar esquematico si es necesario.
Deliverables:
- [x] Link to PCB.
- [x] Link to Schematic.

Josecisneros001, 2021-02-24:
Link To Schematic & PCB: v1.0
(OSHWLAB)[https://oshwlab.com/joseacisnerosm1/homebase-atmega2560]

Josecisneros001, 2021-02-24:
@AldoSamaniego Take a look at this!

Josecisneros001, 2021-03-10:
Add 8 digital output pins for general usage. @AldoSamaniego

Closed 2021-04-07.

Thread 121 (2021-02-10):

Schematic Elevador

Josecisneros001, 2021-02-10:
Objectives:
- Develop Schematic in EasyEda.
Deliverables:
- [x] Link EasyEda

AnelAlvarado, 2021-02-24:
https://oshwlab.com/AnelAlvarado/driverelevador

Josecisneros001, 2021-02-24:
@AminMendez @AldoSamaniego Review this schematic.

Closed 2021-04-07.

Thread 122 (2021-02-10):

Top part of the elevator

AldoSamaniego, 2021-02-10:
Objectives:
Fix and make improvements of the top part of the elevator
Deliverables:
SolidWorks CAD

Josecisneros001, 2021-03-10:
@AldoSamaniego @AminMendez take a look at this.

AldoSamaniego, 2021-06-17:
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

BVDozen, 2021-10-02:
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
Soporte universal para micrófono utilizando velcro
Agujeros para display

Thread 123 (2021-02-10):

Research of gripper and feedback

AldoSamaniego, 2021-02-10:
Objectives:
Research about the gripper and the arm position feedback system.
Deliverables:
Doc about the research

Josecisneros001, 2021-02-24:
https://docs.google.com/document/d/18NhwvxsXx4StxQHB3NhMZ1VpiOLH5z3mmXlt-CJNE3o/edit?usp=sharing

Closed 2021-02-24.

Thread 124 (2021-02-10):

Bottom part of the elevator

AldoSamaniego, 2021-02-10:
Objectives:
Fix and make improvements of the button part of the elevator
Deliverables:
SolidWorks CAD

Josecisneros001, 2021-03-10:
@AminMendez @AldoSamaniego take a look at the integration of this.

Josecisneros001, 2021-04-07:
Reference: #141

Closed 2021-09-18.

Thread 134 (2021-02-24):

Investigación Fibra Vidrio

Josecisneros001, 2021-02-24:
Desarrollar documento sobre la manufactura de fibra de vidrio.
Ver posibilidad de empezar pruebas
- Investigar método (molde + manejo de fibra)
- Desarrollar BOM
- Ver dónde podría fabricarse molde (waterjet)

AuroTB, 2021-03-12:
Documentación de fibra de vidrio: https://docs.google.com/document/d/158ci4uIg3gkiYWl_m8CAxykUG-NU0_C73wTkkfxpXmY/edit#heading=h.h24cbcnw50rf

Closed 2021-03-24.

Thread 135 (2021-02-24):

Desarrollo Suspensión

Josecisneros001, 2021-02-24:
- Diseño de Suspensión para mejorar agarre

Entregable:
- [ ]  Investigación/Cálculos
- [ ] Modelaje Solidworks

AminMendez, 2021-03-10:
To begin the model of the robot suspension system first we need to calculate the teoretical values of the spring and damping constants that satisfy a smood displacement. Mathematical modeling of the four wheel system is complicated. We can simplify the sistem by only analysing one wheel as show below.

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

A mass-spring damper system is model by the following equation:

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

where m is the mass that holds a wheel, K the spring constant, b the damping coeficient and r(t) the external forces.

Using Laplace transform we can conclude:

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

The transfer function is given by:

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

Once having the model of the system we substitute the values we have, such as the mass. As we want a smood movement the
spring must be a systm with critical damping, So the poles of the system must be equals:

s^2 +(b/m)*s + (k/m) = (s + p)^2

giving us the value of b as function of k and m

b= 2* m* sqrt (k/m)

By using Matlab and WolframAlpha programs I model the system to give the reaction of any input to the system with knowing the constants.
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

My task of this week is to find the most suitable constant K for our robot, mantaining the desire stability.

AminMendez, 2021-04-21:
Continuing with the calculus of the suspension, We develop a MATLAB program in which by a given estability time we can know the values of the spring and damping constants. The first program is simulating a Step input with a variable magnitud and the second we can give the traslational function of the wheel.

UNIT STEP
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

Response with unit step magnitud of 10
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

Given Function
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

Response with Sin (t) input
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

Now by just given the Stability Time we can know the important constants  with a critical damping

AldoSamaniego, 2021-06-17:
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

Closed 2023-11-03.

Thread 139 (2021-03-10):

Gripper v1

Josecisneros001, 2021-03-10:
- Desarrollar v1.0 Gripper

Entregable
- [x] Foto/Link Cad

AlonRuiz, 2021-03-24:
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

The parts and assembly shown above can be found in the shared OneDrive folder at: atHome>Brazo>Pinza.

Josecisneros001, 2021-04-07:
Working on:
- Servos Improvement

AlonRuiz, 2021-04-13:
Design report: Gripper Iterations

https://docs.google.com/document/d/12_VXpYMRWF4WLSRXYkXUYQPO0zy17tIpcvqSBW9r7Bc/edit?usp=sharing

AldoSamaniego, 2021-06-17:
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

Closed 2021-09-18.

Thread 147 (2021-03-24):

PCB Development Elevador

Josecisneros001, 2021-03-24:
De acuerdo al esquematico: []
Poner a disposición:
 - 5V, 12V
 - Pines que no se usan del microcontrolador.
 - Pines I2C

Josecisneros001, 2021-04-14:
https://oshwlab.com/AnelAlvarado/driverelevador

Closed 2023-11-03.

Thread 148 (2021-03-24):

PCB Development Brazo

Josecisneros001, 2021-03-24:
De acuerdo al esquemático: []
Poner a disposición:
 - 5V, 12V
 - Pines que no se usan del microcontrolador.
 - Pines I2C

andrea2702, 2021-04-06:
https://oshwlab.com/a00831510/brazo_control_Home

Closed 2023-11-03.

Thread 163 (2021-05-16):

TMR 2021

Josecisneros001, 2021-05-16:
Integración
- [x] Desarrollar nodos para publicar devices
- [x] Setup de jetson Noetic Ubuntu 20
- [ ] Desarrollo de action client para nav

Main Engine}
- [x] Bring up de retos individual

Navigation
- [x] Mapeo
- [x] Contextualizacion de ambiente
- [ ] Action server nav

Vision
- [ ] Desarrollar topico de feedback

Speech
- [ ] Testing de speech en nueva red y publicacion de device

Conversation
- [x] Reto extra
- [x] Debuggear funcionamiento de intents

Mecánica
- [ ] Montar devices en robot
- [ ] Cámara por cuenta de zoom en pista

Closed 2023-11-03.

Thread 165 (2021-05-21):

Home Education 2021

andrea2702, 2021-05-21:
Deliverables:
- [ ] TDP (Team description paper)
- [ ] Team poster + presentation of technical development

**Task 1**
Visión
- [ ] Detectar bolsa
- [ ] Detectar obstáculos  (personas, objetos pequeños en el piso)

Mecánica
- [ ] Tomar bolsa

Navegación
- [ ] Seguir al operador

Bonus
- [ ] Volver al punto de inicio
- [ ] Regresar a la arena

**Task 2**
Vision
- [ ] Detectar a la persona

Navegación
- [ ] Moverse frente a la persona
- [ ] Dar ubicacion de la persona

Speech
- [ ] Dar nombre correcto de la persona
- [ ] Dar descripcion correcta de 2 personas
**_Bonus_**
- [ ] Nombre y descripción de tercera persona

**Task 3**
Speech
- [ ] Introducir a 2 invitados  (nombre y bebida favorita)

Navegacion
- [ ] Apuntar al invitado
- [ ] Apuntar a asiento vacio

Vision
- [ ] Detectar un asiento libre

_**Bonus**_
- [ ] Abrir puerta al invitado
- [ ] Sentar a la persona mas vieja en el sofa

**Notas**

**_Set up and demostration_**
7 minutos maximos de set up, presentacion y demostracion
**_Interview and celan up_**
3 minutos para responder preguntas. Durante el tiempo deshacer cambios hechos por el equipo a la pista.

Closed 2023-11-03.

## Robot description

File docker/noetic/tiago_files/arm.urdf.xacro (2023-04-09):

<?xml version="1.0"?>
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

<robot xmlns:xacro="http://ros.org/wiki/xacro">

  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
  <xacro:include filename="$(find tiago_description)/urdf/deg_to_rad.xacro" />
  <xacro:include filename="$(find tiago_description)/urdf/arm/wrist.urdf.xacro" />
  <xacro:include filename="$(find tiago_description)/urdf/arm/arm.transmission.xacro" />

  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
  <xacro:property name="arm_friction" value="1.0" />
  <xacro:property name="arm_damping" value="1.0" />
  <xacro:property name="arm_1_max_vel" value="1.95" />
  <xacro:property name="arm_2_max_vel" value="1.95" />
  <xacro:property name="arm_3_max_vel" value="2.35" />
  <xacro:property name="arm_4_max_vel" value="2.35" />
  <xacro:property name="arm_1_max_effort" value="43.0" />
  <xacro:property name="arm_2_max_effort" value="43.0" />
  <xacro:property name="arm_3_max_effort" value="26" />
  <xacro:property name="arm_4_max_effort" value="26" />


  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
  <xacro:macro name="tiago_arm" params="name parent wrist_model has_ft_sensor reflect tiago_dual *origin arm_1_offset arm_2_offset arm_3_offset arm_4_offset arm_5_offset arm_6_offset arm_7_offset no_safety_eps:=False">
   <xacro:property name="arm_eps" value="${0.00 if no_safety_eps else 0.07}"/>

    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
    <link name="${name}_1_link">
      <inertial>
        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
        <origin xyz="0.061191 -0.022397 ${reflect * -0.012835}" rpy="0.00000 0.00000 0.00000"/>
        <mass value="1.563428"/>
        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
      </inertial>
      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
    </link>

    <joint name="${name}_1_joint" type="revolute">
      <parent link="${parent}" />
      <child link="${name}_1_link" />
      <xacro:insert_block name="origin"/>
      <axis xyz="0 0 1" />
      <xacro:property name="arm_1_upper_limit" value="${90.0 if tiago_dual == 1 else 157.5}"/>
      <xacro:property name="arm_1_lower_limit" value="${-67.5 if tiago_dual == 1 else 0.0}"/>
      <limit lower="${arm_1_lower_limit * deg_to_rad}" upper="${arm_1_upper_limit * deg_to_rad}" effort="${arm_1_max_effort}" velocity="${arm_1_max_vel}" />
      <dynamics friction="${arm_friction}" damping="${arm_damping}"/>

      <safety_controller k_position="20" k_velocity="20" soft_lower_limit="${arm_1_lower_limit * deg_to_rad + arm_eps}" soft_upper_limit="${arm_1_upper_limit * deg_to_rad - arm_eps}" />
    </joint>

   <link name="${name}_2_link">
      <inertial>
        <origin xyz="0.030432 0.000229 ${reflect * -0.005942}" rpy="0.00000 0.00000 0.00000"/>
        <mass value="1.800397"/>
        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
      </inertial>
      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
    </link>

    <joint name="${name}_2_joint" type="revolute">
      <parent link="${name}_1_link" />
      <child link="${name}_2_link" />
      <origin xyz="0.125 ${tiago_dual * -0.0195} ${reflect * -0.031}" rpy="${reflect * tiago_dual * -90.0 * deg_to_rad} 0.0 0.0"/>
      <axis xyz="0 0 1" />
      <xacro:property name="arm_2_upper_limit" value="${90.0 if tiago_dual == 1 else 62.5}"/>
      <xacro:property name="arm_2_lower_limit" value="${-67.5 if tiago_dual == 1 else -90.0}"/>
      <limit lower="${arm_2_lower_limit * deg_to_rad}" upper="${arm_2_upper_limit * deg_to_rad}" effort="${arm_2_max_effort}" velocity="${arm_2_max_vel}" />
      <dynamics friction="${arm_friction}" damping="${arm_damping}"/>

      <safety_controller k_position="20" k_velocity="20" soft_lower_limit="${arm_2_lower_limit * deg_to_rad + arm_eps}" soft_upper_limit="${ arm_2_upper_limit * deg_to_rad - arm_eps}" />
    </joint>

    <link name="${name}_3_link">
      <inertial>
        <origin xyz="0.007418 -0.004361 ${reflect * -0.134194}" rpy="0.00000 0.00000 0.00000"/>
        <mass value="1.8"/>
        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
      </inertial>
      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
    </link>

    <joint name="${name}_3_joint" type="revolute">
      <parent link="${name}_2_link" />
      <child link="${name}_3_link" />
      <origin xyz="0.0895 0.0 -0.0015" rpy="${-90.0 * deg_to_rad} ${(90.0 - reflect * 90.0) * deg_to_rad} ${reflect * 90.0 * deg_to_rad}"/>
      <axis xyz="0 0 1" />
      <xacro:property name="arm_3_lower_limit" value="${-45. if tiago_dual == 1 else -202.5}"/>
      <xacro:property name="arm_3_upper_limit" value="${225 if tiago_dual == 1 else 90.0}"/>
      <limit lower="${arm_3_lower_limit * deg_to_rad}" upper="${arm_3_upper_limit * deg_to_rad}" effort="${arm_3_max_effort}" velocity="${arm_3_max_vel}" />
      <dynamics friction="${arm_friction}" damping="${arm_damping}"/>

      <safety_controller k_position="20" k_velocity="20" soft_lower_limit="${arm_3_lower_limit * deg_to_rad + arm_eps}" soft_upper_limit="${ arm_3_upper_limit * deg_to_rad - arm_eps}" />
    </joint>

    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
    <link name="${name}_4_link">
      <inertial>
        <origin xyz="${reflect * -0.095658} ${reflect * 0.014666} ${reflect * 0.018133}" rpy="0.00000 0.00000 0.00000"/>
        <mass value="1.432697"/>
        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
      </inertial>
      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
    </link>

    <joint name="${name}_4_joint" type="revolute">
      <parent link="${name}_3_link" />
      <child link="${name}_4_link" />
      <origin xyz="-0.02 -0.027 ${reflect * -0.222}" rpy="${reflect * -90.0 * deg_to_rad} ${-90.0 * deg_to_rad} ${0.0 * deg_to_rad}"/>
      <axis xyz="0 0 1" />
      <limit lower="${-22.5 * deg_to_rad}" upper="${135 * deg_to_rad}" effort="${arm_4_max_effort}" velocity="${arm_4_max_vel}" />
      <dynamics friction="${arm_friction}" damping="${arm_damping}"/>

      <safety_controller k_position="20" k_velocity="20" soft_lower_limit="${ -22.5 * deg_to_rad + arm_eps}" soft_upper_limit="${ 135 * deg_to_rad - arm_eps}" />
    </joint>

   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

   <xacro:wrist name="${name}" parent="${name}_4_link" reflect="${reflect}" wrist_model="${wrist_model}" has_ft_sensor="${has_ft_sensor}" arm_5_offset="${arm_5_offset}" arm_6_offset="${arm_6_offset}" arm_7_offset="${arm_7_offset}" no_safety_eps="${no_safety_eps}"/>

    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
    <link name="${name}_tool_link">
      <inertial>
        <mass value="0.1" />
        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
      </inertial>
      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
    </link>

    <xacro:if value="${wrist_model == 'wrist-2010'}">
      <xacro:property name="tool_link_z_offset" value="0.046"/>
    </xacro:if>
    <xacro:if value="${wrist_model == 'wrist-2017'}">
     <xacro:property name="tool_link_z_offset" value="${ 0.046 if has_ft_sensor else 0.0573 }"/>
    </xacro:if>
    <joint name="${name}_tool_joint" type="fixed">
      <parent link="${name}_7_link" />
      <child link="${name}_tool_link" />
        <origin xyz="0 0 ${reflect * tool_link_z_offset}" rpy="${90.0 * deg_to_rad} ${reflect * -90.0 * deg_to_rad} ${180 * deg_to_rad}" />
    </joint>

    <link name="end_effector_link">
    </link>
    <joint name="end_effector_joint" type="fixed">
      <parent link="${name}_tool_link" />
      <child link="end_effector_link" />
      <origin xyz="0.17 0 0" rpy="0 0 0" />
    </joint>

    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
    <xacro:arm_simple_transmission name="${name}" number="1" reduction="1.0" offset_value="${arm_1_offset}"/>
    <xacro:arm_simple_transmission name="${name}" number="2" reduction="1.0" offset_value="${arm_2_offset}"/>
    <xacro:arm_simple_transmission name="${name}" number="3" reduction="1.0" offset_value="${arm_3_offset}"/>
    <xacro:arm_simple_transmission name="${name}" number="4" reduction="1.0" offset_value="${arm_4_offset}"/>
  </xacro:macro>

</robot>

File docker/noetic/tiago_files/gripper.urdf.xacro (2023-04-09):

<?xml version="1.0"?>

<robot xmlns:xacro="http://ros.org/wiki/xacro">

  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
  <xacro:include filename="$(find pal_gripper_description)/urdf/deg_to_rad.urdf.xacro" />
  <xacro:include filename="$(find pal_gripper_description)/urdf/gripper.transmission.xacro" />
  <xacro:include filename="$(find pal_gripper_description)/urdf/gripper.gazebo.xacro" />

  <xacro:property name="gripper_eps" value="0.001" />

  <xacro:macro name="pal_gripper" params="name parent *origin">

  <xacro:macro name="gazebo_gripper_grasp" params="name name_prefix_left name_prefix_right parent_joint">
    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
  </xacro:macro>


  <link name="${name}_link">
    <inertial>
      <origin rpy="0.0 0.0 0.0" xyz="-0.000294 0.000291 -0.033086" />
      <mass value="0.602660" />
      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
    </inertial>
    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
  </link>
  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

  <joint name="${name}_joint" type="fixed">
    <xacro:insert_block name="origin"/>
    <parent link="${parent}" />
    <child link="${name}_link" />
    <axis xyz="0 0 0" />
  </joint>

  <link name="${name}_right_finger_link">
    <inertial>
      <origin rpy="0 0 0" xyz="-0.004470 0.010766 -0.121013" />
      <mass value="0.109980" />
      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
    </inertial>
    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
  </link>
  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

  <joint name="${name}_right_finger_joint" type="prismatic">
    <origin rpy="0 0 0" xyz="0. 0 0" />
    <parent link="${name}_link" />
    <child link="${name}_right_finger_link" />
    <axis xyz="1 0 0" />
    <limit effort="64" lower="0.0" upper="0.045" velocity="0.05" />
    <calibration rising="0.0" />
    <dynamics damping="1" />
    <safety_controller k_position="20" k_velocity="20" soft_lower_limit="${0.0 + gripper_eps}" soft_upper_limit="${0.045 - gripper_eps}" />
  </joint>

  <link name="${name}_left_finger_link">
    <inertial>
      <origin rpy="0 0 0" xyz="-0.004470 0.010766 -0.121013" />
      <mass value="0.109980" />
      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
    </inertial>
    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
  </link>
  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

  <joint name="${name}_left_finger_joint" type="prismatic">
    <origin rpy="0 0 0" xyz="0. 0 0" />
    <parent link="${name}_link" />
    <child link="${name}_left_finger_link" />
    <axis xyz="-1 0 0" />
    <limit effort="64" lower="0" upper="0.045" velocity="0.05" />
    <calibration rising="0.0" />
    <dynamics damping="1" />
    <safety_controller k_position="20" k_velocity="20" soft_lower_limit="${0.0 + gripper_eps}" soft_upper_limit="${0.045 - gripper_eps}" />
  </joint>

  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
  <joint name="${name}_grasping_frame_joint" type="fixed">
    <parent link="${name}_link" />
    <child link="${name}_grasping_frame" />
    <origin xyz="0 0 -0.12" rpy="-1.5708 1.5708 0" />
  </joint>
  <link name="${name}_grasping_frame">
    <inertial>
      <origin xyz="0 0 0" rpy="0 0 0" />
      <mass value="0.0001" />
      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
    </inertial>
  </link>

  <xacro:gripper_simple_transmission name="${name}_left_finger" reduction="1.0"/>
  <xacro:gripper_simple_transmission name="${name}_right_finger" reduction="1.0"/>

  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
  <xacro:gazebo_gripper_grasp name="${name}_grasp" name_prefix_left="${name}_left_finger_link" name_prefix_right="${name}_right_finger_link" parent_joint="${parent}"/>

  <xacro:finger_gazebo name="${name}_left_finger"/>
  <xacro:finger_gazebo name="${name}_right_finger"/>

 </xacro:macro>

</robot>

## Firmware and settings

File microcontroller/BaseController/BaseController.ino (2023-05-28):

#include "Movement.h"
#include "RosBridge.h"
#include "BNO.h"
#include "Plot.h"

Movement *robot = nullptr;
bool ROS_ENABLE = true;
bool CHECK_PID = false;
bool CHECK_MOTORS = false;
bool CHECK_ENCODERS = false;

void setup() {
    Serial.begin(57600);
    Serial2.begin(57600);

    Movement initRobot;
    robot = &initRobot;
    robot->initEncoders();

    if (!ROS_ENABLE) {
        loop();
    }
    
    BNO bno;
    Plot plot(robot, ROS_ENABLE);
    // plot.startSequence();
    
    RosBridge bridge(robot, &bno, &plot);
    
    bridge.run();
}

// Used if ROS disabled.
void loop() {
    if (CHECK_PID) {
        Serial.begin(57600);
        // Check PID
        while(1) {
            Plot plot(robot, !ROS_ENABLE);
            delay(2000);
            plot.startSequence();
            // List of x Velocities
            double xVelocities[] = {0.1, 0.2, 0.3, 0.4, 0.5, 0.6, 0.7};
            long long time = 0.0;
            int i = 0;
            bool sign = false;
            while(1) {
                if (millis() - time > 6000) {
                    time = millis();
                    if (sign) {
                      i++;
                      if (i == 7) {
                          i = 0;
                      }
                      sign = false;
                    }else {
                      sign = true;
                    }
                }
                robot->cmdVelocity(0.5, 0, 0);
                plot.plotTargetandCurrent();
            }
        }
    }
    if (CHECK_ENCODERS) {
        Serial.begin(9600);
        bool direction = false;
        long long start_time = millis();
        while(1) {
          if (millis() - start_time > 10*1000) {
            start_time = millis();
            direction = !direction;
            Serial.println("Direction Changed");
          }
          if (direction) {
            robot->back_left_motor_.changePwm(150);
            robot->back_left_motor_.forward();
            robot->front_left_motor_.changePwm(150);
            robot->front_left_motor_.forward();
            robot->back_right_motor_.changePwm(150);
            robot->back_right_motor_.forward();
            robot->front_right_motor_.changePwm(150);
            robot->front_right_motor_.forward();
          } else {
            robot->back_left_motor_.changePwm(150);
            robot->back_left_motor_.backward();
            robot->front_left_motor_.changePwm(150);
            robot->front_left_motor_.backward();
            robot->back_right_motor_.changePwm(150);
            robot->back_right_motor_.backward();
            robot->front_right_motor_.changePwm(150);
            robot->front_right_motor_.backward();
          }
               
          Serial.print("BL ");
          Serial.println( (robot->back_left_motor_.getEncodersDir()));
          Serial.print("FL ");
          Serial.println( (robot->front_left_motor_.getEncodersDir()));
          Serial.print("BR ");
          Serial.println( (robot->back_right_motor_.getEncodersDir()));
          Serial.print("FR ");
          Serial.println( (robot->front_right_motor_.getEncodersDir()));
          Serial.println("\n");
        }
    }
    
    if (CHECK_MOTORS) {
        Serial.begin(9600);
        // Check Motors
        while(1) {
          long long start = millis();
          robot->back_left_motor_.setPidTicks(0);
          robot->front_left_motor_.setPidTicks(0);
          robot->back_right_motor_.setPidTicks(0);
          robot->front_right_motor_.setPidTicks(0);
          while(millis()-start < 1000) {
              robot->back_left_motor_.changePwm(255);
              robot->back_left_motor_.forward();
              robot->front_left_motor_.changePwm(255);
              robot->front_left_motor_.forward();
              robot->back_right_motor_.changePwm(255);
              robot->back_right_motor_.forward();
              robot->front_right_motor_.changePwm(255);
              robot->front_right_motor_.forward();
          }
          robot->back_left_motor_.changePwm(0);
          robot->back_right_motor_.changePwm(0);
          robot->front_left_motor_.changePwm(0);
          robot->front_right_motor_.changePwm(0);
          Serial.print("BL");
          Serial.println( (robot->back_left_motor_.getPidTicks() / Motor::kPulsesPerRevolution) * 60 );
          Serial.print("FL");
          Serial.println( (robot->front_left_motor_.getPidTicks() / Motor::kPulsesPerRevolution) * 60 );
          Serial.print("BR");
          Serial.println( (robot->back_right_motor_.getPidTicks() / Motor::kPulsesPerRevolution) * 60 );
          Serial.print("FR");
          Serial.println( (robot->front_right_motor_.getPidTicks() / Motor::kPulsesPerRevolution) * 60 );
          delay(1000);
        }
    }
}

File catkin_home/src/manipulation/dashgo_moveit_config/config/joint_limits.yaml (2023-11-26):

# joint_limits.yaml allows the dynamics properties specified in the URDF to be overwritten or augmented as needed

# For beginners, we downscale velocity and acceleration limits.
# You can always specify higher scaling factors (<= 1.0) in your motion requests.  # Increase the values below to 1.0 to always move at maximum speed.
# default_velocity_scaling_factor: 0.3
# default_acceleration_scaling_factor: 0.1

# Specific joint properties can be changed with the keys [max_position, min_position, max_velocity, max_acceleration]
# Joint limits can be turned off with [has_velocity_limits, has_acceleration_limits]
joint_limits:
  Cam1Rev1:
    has_velocity_limits: false
    max_velocity: 0
    has_acceleration_limits: false
    max_acceleration: 0
  Cam1Rev2:
    has_velocity_limits: false
    max_velocity: 0
    has_acceleration_limits: false
    max_acceleration: 0
  Rev1Servo:
    has_velocity_limits: false
    max_velocity: 0
    has_acceleration_limits: false
    max_acceleration: 0
  Rev2Servo:
    has_velocity_limits: false
    max_velocity: 0
    has_acceleration_limits: false
    max_acceleration: 0
  joint1:
    has_velocity_limits: true
    max_velocity: 2.14
    has_acceleration_limits: false
    max_acceleration: 0
    #max_position: 0.785
    #min_position: -3.14
  joint2:
    has_velocity_limits: true
    max_velocity: 2.14
    has_acceleration_limits: false
    max_acceleration: 0
  joint3:
    has_velocity_limits: true
    max_velocity: 2.14
    has_acceleration_limits: false
    max_acceleration: 0
  joint4:
    has_velocity_limits: true
    max_velocity: 2.14
    has_acceleration_limits: false
    max_acceleration: 0
    #max_position: 3.14
    #min_position: -3.14
  joint5:
    has_velocity_limits: true
    max_velocity: 2.14
    has_acceleration_limits: false
    max_acceleration: 0
  joint6:
    has_velocity_limits: true
    max_velocity: 2.14
    has_acceleration_limits: false
    max_acceleration: 0
    #max_position: 3.14
    #min_position: -3.14
  odom_r:
    has_velocity_limits: true
    max_velocity: 0.18
    has_acceleration_limits: false
    max_acceleration: 0
  odom_x:
    has_velocity_limits: true
    max_velocity: 0.08
    has_acceleration_limits: false
    max_acceleration: 0
  odom_y:
    has_velocity_limits: true
    max_velocity: 0.08
    has_acceleration_limits: false
    max_acceleration: 0

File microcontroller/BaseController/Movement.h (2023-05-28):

// This class has all the functions related to Movement.
#ifndef Movement_h
#define Movement_h

#include "MotorId.h"

#include "Kinematics.h"
#include <math.h>
#include <Arduino.h>

#include "Motor.h"

enum class Direction{
    left = 1,
    right = 2 
};

class Movement {
  public:
    //////////////////////////////////Constructor//////////////////////////////////////
    Movement();


    //////////////////////////////////Motors//////////////////////////////////////
    Motor back_right_motor_;
    Motor back_left_motor_;
    Motor front_right_motor_;
    Motor front_left_motor_;
    int kMotorCount = 4;

    //////////////////////////////////Encoders//////////////////////////////////////
    // Initialize motor encoders.
    void initEncoders();


    //////////////////////////////////PWM//////////////////////////////////////
    // Set same pwm to all motors.
    void changePwm(const uint8_t pwm);


    //////////////////////////////////VELOCITY//////////////////////////////////////
    // Change deltaX value.
    void setDeltaX(const double delta_x);
    
    // Change deltaY value.
    void setDeltaY(const double delta_y);
    
    // Change deltaAngular value.
    void setDeltaAngular(const double delta_angular);

    // Return deltaX value.
    double getDeltaX();
    
    // Return deltaY value.
    double getDeltaY();
    
    // Return deltaAngular value.
    double getDeltaAngular();
    
    // Stop robot.
    void stop();
    
    //////////////////////////////////PID//////////////////////////////////////
    // Robot linear velocity to rpm per motor. 
    void cmdVelocity(const double linear_x, const double linear_y, const double angular_z);
    
    // Set motors to velocity. 
    void updatePIDKinematics(double fl_speed, double fr_speed, double bl_speed, double br_speed);

  private:
  
    //////////////////////////////////DIRECTIONS//////////////////////////////////////
    // Convert radians to degrees.
    double radiansToDegrees(const double radians);

    // Pins,
    static constexpr uint8_t kDigitalPinsFrontLeftMotor[2] = {15, 14};
    static constexpr uint8_t kAnalogPinFrontLeftMotor = 11;
    static constexpr uint8_t kEncoderPinsFrontLeftMotor[2] = {3, 49};

    static constexpr uint8_t kDigitalPinsBackLeftMotor[2] = {23, 22};
    static constexpr uint8_t kAnalogPinBackLeftMotor = 6;
    static constexpr uint8_t kEncoderPinsBackLeftMotor[2] = {2, 48};

    static constexpr uint8_t kDigitalPinsFrontRightMotor[2] = {26,27};
    static constexpr uint8_t kAnalogPinFrontRightMotor = 7;
    static constexpr uint8_t kEncoderPinsFrontRightMotor[2] = {19, 45};

    static constexpr uint8_t kDigitalPinsBackRightMotor[2] = {30,31};
    static constexpr uint8_t kAnalogPinBackRightMotor = 8;
    static constexpr uint8_t kEncoderPinsBackRightMotor[2] = {18, 44};

    // Velocity maximum.
    static constexpr double kFrWheelsDist = 0.0;
    static constexpr double kLrWheelsDist = 0.33;
    static constexpr double kWheelDiameter = 0.12;
    static constexpr double kRPM = 120;
    static constexpr double kRPS = kRPM / 60;
    static constexpr double kMaxVelocity = kRPS * (M_PI * kWheelDiameter);

    static constexpr double kLinearXMaxVelocity = kMaxVelocity;
    static constexpr double kLinearYMaxVelocity = kMaxVelocity;
    static constexpr double kAngularZMaxVelocity = kMaxVelocity / kLrWheelsDist;
    static constexpr uint8_t kPwmBits = 8;
    long long cycle = 0;

    // Kinematics.
    Kinematics kinematics_;

    // Velocity.
    double delta_x_ = 0;
    double delta_y_ = 0;
    double delta_angular_ = 0;
};
#endif

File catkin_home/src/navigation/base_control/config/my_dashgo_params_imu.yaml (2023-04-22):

#port: /dev/ttyUSB0
port: /dev/ttyACM0 
baud: 57600
timeout: 0.1
rate: 50
sensorstate_rate: 10
slam_project_version: 1.1

useImu: True
imu_offset: 1.005

useSonar: False
use_base_controller: True
base_controller_rate: 30 #10


sonar_height: 0.15
sonar_safe_distance: 8
sonar_dec_distance: 40.0  ##decelerate

sonar0_switch: 0
sonar0_offset_yaw: 3.14
sonar0_offset_x: -0.091
sonar0_offset_y: -0.11

sonar1_switch: 1
sonar1_offset_yaw: -0.70
sonar1_offset_x: 0.265
sonar1_offset_y: -0.128

sonar2_switch: 1
sonar2_offset_yaw: 0.0
sonar2_offset_x: 0.27
sonar2_offset_y: 0.0

sonar3_switch: 1
sonar3_offset_yaw: 0.70 
sonar3_offset_x: 0.265
sonar3_offset_y: 0.128

sonar4_switch: 1
sonar4_offset_yaw: 3.14
sonar4_offset_x: -0.091
sonar4_offset_y: 0.11

# For a robot that uses base_footprint, change base_frame to base_footprint
#base_frame: base_link
base_frame: base_footprint

# === Robot drivetrain parameters
wheel_diameter: 0.1230
wheel_track: 0.31
encoder_resolution: 300
gear_reduction: 1.0
motors_reversed: False

# === Turn and Linear
min_rotation_speed: 0.15
max_rotation_speed: 1.5
rotation_accel: 0.8
rotation_decel: 1.6
move_accel: 0.8
move_decel: 1.0
primary_threshold: 0.3
secondary_threshold: 0.2

# === PID parameters
Kp: 50
Kd: 20
Ki: 0
Ko: 50
accel_limit: 1.0

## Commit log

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2019-05-05 Fix style and add collection of frames for rnnoise.
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2020-01-15 Fix missing constant FRAME_SIZE and rename MS_FRAME
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2020-02-27 - Changes the definition of action_selectors_msg in intercom to fit new design of main_engine - Defines class Main_Engine that will handle the central logic of the robot - parser now only sends the i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
    [possible_actions.csv]
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2020-03-02 - Renamed ActionKnights to just Action - logic for deciding which action has more priority done
    [possible_actions.csv]
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2020-03-05 Added Action Client functions to Action class
    [possible_actions.csv]
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2020-03-09 Change callbacks in ObjectDetector to avoid delayed msgs by using a timer callback instead
2020-03-10 Deleted Vizbox Moved the action verification from main_engine to the parser Bring_something now triggers multiple actions Action Queue is now a regular queue KISS
    [possible_actions.csv]
2020-03-13 Fix prints in InputAudio
2020-03-13 Added mapping packages and robot description
    [AssemblyVersion_3.SLDASM.csv, robot_description.urdf]
2020-03-17 Refactor declarations and definitions in .hpp and .cpp in devices/
    This mainly because definitions in the same header file doesn't seem to work because of a 'multiple definitions' erros appear.
2020-04-12 replace i++ with ++i
    [BNO.h, Movement.h]
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2020-04-12 general brackets correction
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2020-04-12 spacing in comments correction
    [BNO.h, Movement.h, Odometry.h]
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2020-04-13 Deleted unused packages for nav action server.
    [AssemblyVersion_3.SLDASM.csv, robot_description.urdf]
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2020-04-20 Added robot description package, containing URDF state publisher.
    [AssemblyVersion_3.SLDASM.csv, robot_description.urdf]
2020-05-05 Added more possible actions to the csv
    [possible_actions.csv]
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2020-05-06 Added demo of pick_up and put_down interface with main_engine
    [possible_actions.csv]
2020-05-13 Modified nav action server
    [goals.csv]
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2020-09-21 Add calls to the segmentation depth algorithms in ObjectDetector.py
    Add in ObjectDetector.py to call the two depth algorithms at Segmentation.py. For this, include a one-time subscription for the realsense intrinsics. This, effectivily finished the addition of the Intel RealSense Camera and the addition of the depth algorithms; only is missing to include a show_image() utility to visualize in development.
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2020-09-26 small fixes to merge odometry visualization
2020-09-29 Tests Cardozo's code with camera - Fixes the out of bound errors by adding a limit - Improves calling of child process
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2020-10-19 fix base_odom styling issues & make code modular
    [base_odom.cpp]
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2021-02-09 Reset depreceated changes if base_control from develop
    [base_odom.cpp]
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2021-05-11 update Parser
    [possible_actions.csv]
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2021-12-24 move robot description folder
    [AssemblyVersion_3.SLDASM.csv, robot_description.urdf]
2021-12-24 add house with objects
    [model.sdf]
2021-12-24 robot_description init
    [AssemblyVersion_3.SLDASM.csv, astra.stl, materials.xacro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]
2022-01-16 WIP new urdf - first iteration
    [PINZA_DER.STL, PINZA_IZQ.STL, astra.stl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]
2022-03-01 Add gazebo sensors to urdf
    [Cuello.STL, Garra_D.STL, Garra_I.STL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]
2022-03-03 fix simulation & gazebo
    [Camara.STL, robot.gazebo.xacro, robot.urdf.xacro]
2022-03-29 temp gazebo map
    [robot.gazebo.xacro, robot.urdf.xacro]
2022-04-09 fix house simulation
    [Camara.STL, Cuello.STL, Garra_D.STL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]
2022-04-09 remove unused models
    [model.sdf]
2022-04-11 init Detection3D script
    [robot.urdf.xacro]
2022-04-25 init urdf changes
    [robot.urdf.xacro]
2022-04-26 init moveit config
    [fake_controllers.yaml, gazebo_controllers.yaml, joint_limits.yaml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]
2022-04-26 remove arm group
    [fake_controllers.yaml]
2022-05-02 update robot urdf
    [BASE PINZA.STL, BASE_PINZA.STL, Camara.STL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]
2022-05-02 setup octomap & gazebo move controllers
    [fake_controllers.yaml, joint_limits.yaml, robot.gazebo.xacro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]
2022-05-05 reduce stl vertices
    [BASE PINZA.STL, BASE_PINZA.STL, Camara.STL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]
2022-05-07 fix urdf for moveit
    [robot.gazebo.xacro, robot.urdf.xacro, ros_controllers.yaml]
2022-05-07 add robot padding & fix urdf joints
    [robot.gazebo.xacro, robot.urdf.xacro, ros_controllers.yaml]
2022-05-09 add models used for simulation
    [model-1_2.sdf, model-1_3.sdf, model-1_4.sdf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]
2022-05-15 init files
    [SphericalGrasp.cfg]
2022-05-16 fix files
    [SphericalGrasp.cfg]
2022-05-20 init manipulation Server
    [SphericalGrasp.cfg, robot.urdf.xacro]
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2022-05-20 fix urdf
    [robot.urdf.xacro]
2022-05-29 save urdf and remove rb_home_arm related files
    [robot.urdf.xacro]
2023-02-12 save tmr 2022 status
    [SphericalGrasp.cfg, robot.gazebo.xacro, robot.urdf.xacro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]
2023-02-12 remove unused model and pkg
    [model.obj, model.sdf]
2023-02-12 remove unused manipulation elements
    [model.sdf]
2023-02-15 unify packages iros-legacy
    [SphericalGrasp.cfg]
2023-02-15 move package to manipulation folder
    [fake_controllers.yaml, gazebo_controllers.yaml, joint_limits.yaml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]
2023-03-14 add tiago setup files
    [tiago.urdf.xacro]
2023-03-15 default tiago files
    [tiago.srdf.xacro]
2023-03-15 changes to tiago files
    [tiago.srdf.xacro]
2023-03-15 basic urdf tiago
    [tiago.urdf.xacro]
2023-03-20 add controllermanager/hw for base_controller RBRGS
    [base_controller.yaml, tiago.urdf.xacro]
2023-03-20 save tiago files used for base controller
    [controllers_pal-gripper.yaml, controllers_pal-gripper_schunk-ft.yaml, joint_limits.yaml]
2023-03-21 disable odom_x and odom_y
    [tiago.urdf.xacro]
2023-03-23 add head planning group to srdf - Tiago
    [tiago.srdf.xacro]
2023-04-06 dashgo urdf v1
    [Base.STL, Cam.STL, Lidar.STL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]
2023-04-09 pick v1.0 with Tiago
    [arm.urdf.xacro, end_effector.urdf.xacro, gazebo_tiago.urdf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]
2023-04-10 v2.0 dashgo urdf
    [Base.STL, BaseBrazo.STL, Dedo1.STL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]
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2023-04-17 moveit_config + controllers DASHGO
    [Base.STL, BaseBrazo.STL, Cam.STL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]
2023-04-17 Add tiago setup
    [arm.urdf.xacro, controllers_pal-gripper.yaml, controllers_pal-gripper_schunk-ft.yaml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]
2023-04-19 updates Dashgo, invert side
    [Movement.h]
2023-04-20 update urdf, new camera
    [Base.STL, Cam2.STL, Cam2Rev.STL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]
2023-04-25 grasping v1.0
    [BaseGri.STL, Base_Collisions.STL, Cam1RevFix.STL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]
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2023-04-26 carry my luggage WIP, human analyzer
    [DASHGO_controllers.yaml, RBRGS_controllers.yaml, controllers.yaml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]
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2023-04-28 cary my luggage v1, remove base_controller
    [RBRGS_controllers.yaml, controllers.yaml, dashgo.urdf.xacro]
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2023-06-23 add gripper fake sf, remove unused robot_description pkg
    [Base.STL, BaseBrazo.STL, Base_Collisions.STL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]
2023-06-27 modify gpd config to SF gripper
    [dashgo_eigen_params_SF.cfg]
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2023-06-28 manipulation demo june 2023
    [dashgo_eigen_params_SF.cfg, joint_limits.yaml]
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2023-08-28 OMPL collision correction, added Rviz config
    [dashgo_eigen_params_SF.cfg]
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2023-11-01 Arm action server & URDF update
    [BaseCollisionsSinPalo.stl, BaseSinPalo.stl, dashgo.urdf.xacro]
2023-11-02 Cam gripper urdf updated
    [dashgo.urdf.xacro]
2023-11-02 URDF cam gripper updated
    [dashgo.urdf.xacro]
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2023-11-06 Change angle of pose stamped target
    [dashgo_eigen_params_SF.cfg]
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2023-11-17 Arm server added planing and wait=false
    [cubierta.stl, cubierta_colliders.stl]
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2023-11-17 Dashgo urdf updated (testing missing)
    [dashgo.urdf.xacro, dashgo_cubierta.stl, dashgo_cubierta_colliders.stl]
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2023-11-25 Arm server fixed

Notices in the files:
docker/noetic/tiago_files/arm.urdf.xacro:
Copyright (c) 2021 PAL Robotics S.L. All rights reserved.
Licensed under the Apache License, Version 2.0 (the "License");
